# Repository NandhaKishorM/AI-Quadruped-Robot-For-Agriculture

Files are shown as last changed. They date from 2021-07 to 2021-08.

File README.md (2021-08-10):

# AI-Quadruped-Robot-For-Agriculture
## Problem statement
Massive investment on agrochemicals from the farmers’ end on crops for protection against crop health issues, diseases, and pest attacks, leading to high chemical residue content in the final product, thus reducing the quality of the produce, productivity, and polluting the farm environment. Also large use of water into crops leading to unwanted wastage of water.

## Solution
For the farmers cultivating crops, an **OAK-D enabled quadruped robot** with **robotic arm** to effectively spray **water/pesticides/insecticides** on the crops by identifying the **crop or the pests**, thus saving farmers investment on agrochemicals and water, utilizing the depth capability to detect the pest and analyze the pest infection in the process.

# Software Installation - Agribot
We followed the GitHub repo by Mike4192 for this version. Go to this [link](https://github.com/mike4192/spotMicro) to learn more.
The default implementation is on **Raspberry Pi 3 Model B and ROS kinetic**, since we used **Nvidia Jetson Nano** we invested some time on migrating to **ROS melodic**.
After installing ROS melodic on Nvidia Jetson Nano, run,
```sh
git clone https://github.com/kishorkuttan/AI-Quadruped-Robot-For-Agriculture.git
source /opt/ros/kinetic/setup.bash 
mkdir -p ~/catkin_temp  
cp -a /path/to/AI-Quadruped-Robot-For-Agriculture/src/ ~/catkin_temp/
catkin build
source devel/setup.bash
```
If you find errors during catkin build install necessary libraries or directly copy the libraries to **/src/** folder and re run catkin_build

## 3D prints
### Robot
Go to this [link](https://www.thingiverse.com/thing:3445283) for spot micro 3D print files. We made slight modification due to stability and structural issues in the default print.

### Arm
The files are under the folder /Arm 3D print stl files/

## Connection
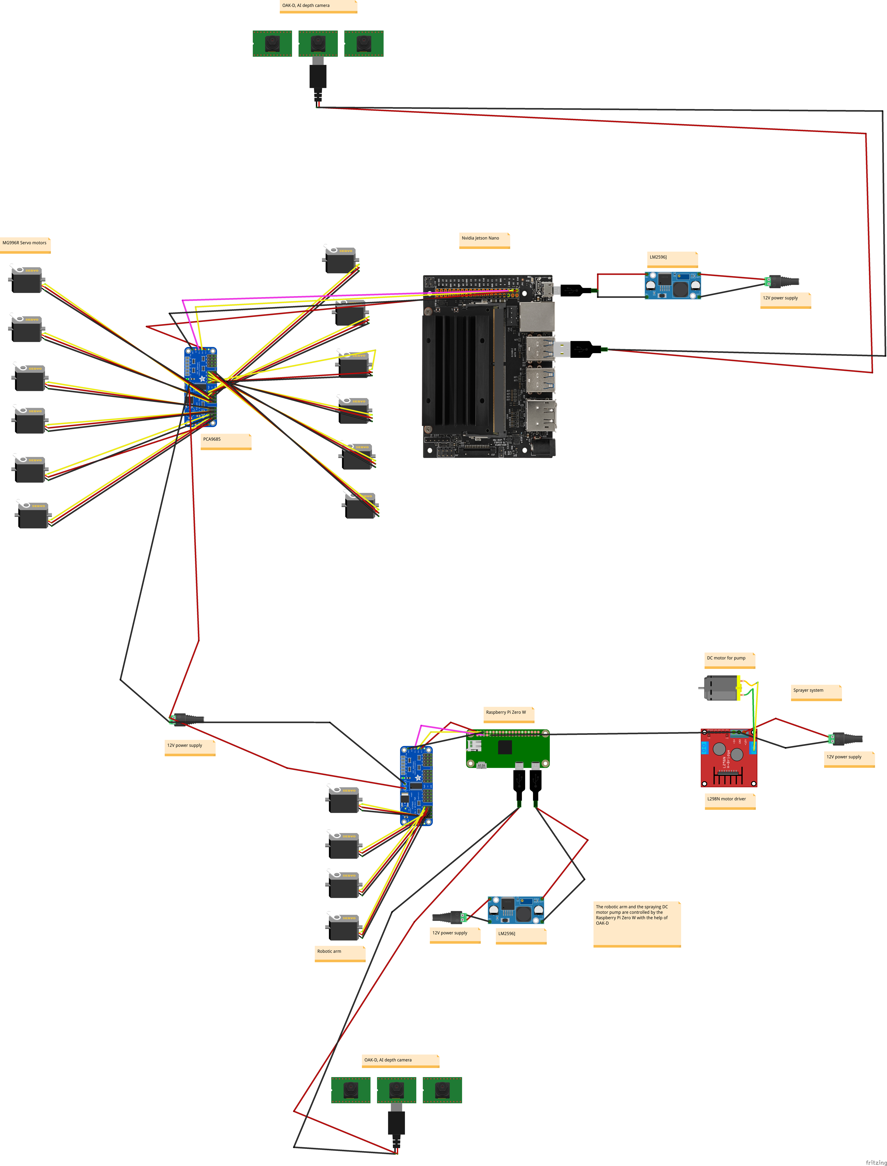
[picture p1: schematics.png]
at text

## The Robotic Arm And Sprayer System
Connect as per the diagram and control the Raspberry Pi Zero W through VNC and run,
```sh
python arm_and_spray.py
```
In this script it calculates angles for servo motors using IK and also starts the DC motor pump after getting the x,y,z location data from OAK-D.

<p float="left">
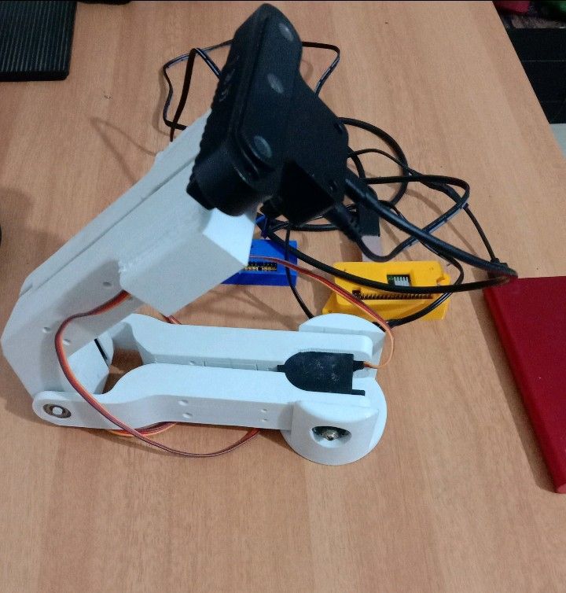
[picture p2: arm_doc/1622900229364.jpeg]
  
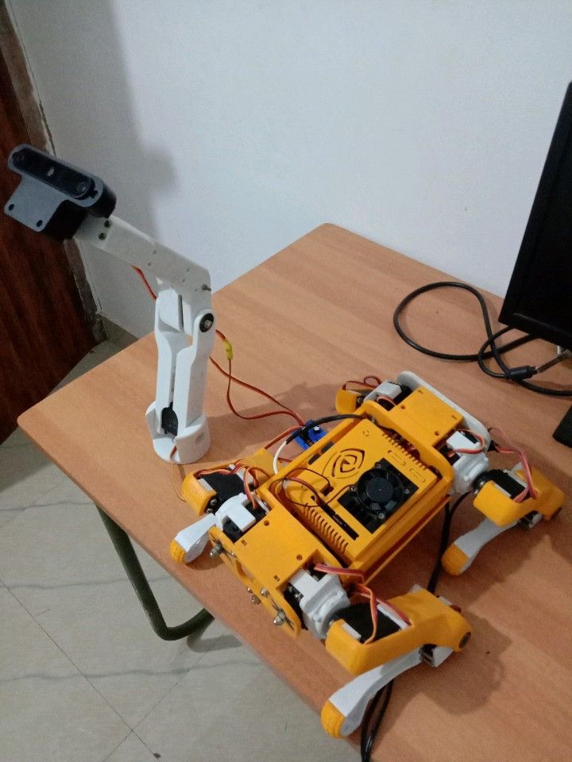
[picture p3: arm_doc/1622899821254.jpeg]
   
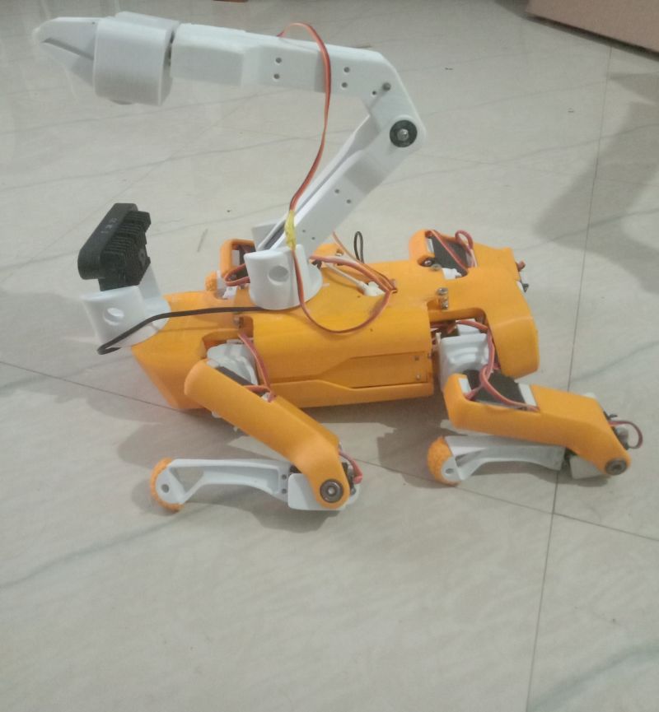
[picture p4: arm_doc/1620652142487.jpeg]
  
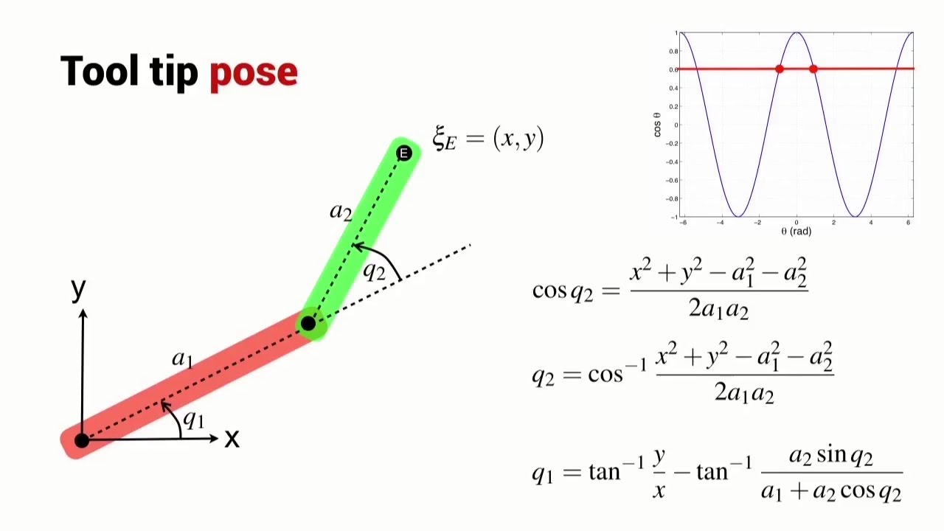
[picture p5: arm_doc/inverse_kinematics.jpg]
    
</p>

### Test OAK-D
connect the OAK-D to the host
```sh
python spatial_mobilenet.py

```
## Demo

https://user-images.githubusercontent.com/48623612/127535646-96b2c777-e888-43cb-af1a-77d663f8487b.mp4

https://user-images.githubusercontent.com/48623612/127535906-9ffb2053-86a3-4153-b496-3118d2ea1060.mp4

https://user-images.githubusercontent.com/48623612/128687662-2845c66a-45d7-49c7-8cf9-19cea187af5c.mp4

### Pest detection
#### Test
```sh
python spatial_mobilenet_custom.py
```
#### Train
Pest detection TensorFlow 1.x pipeline


https://user-images.githubusercontent.com/48623612/128688979-6633d1d9-b441-4c8c-9f94-d753bce6091c.mp4

## Inbuilt OAK-D IMU utilization
Run

```sh
python gyro visualization
```

https://user-images.githubusercontent.com/48623612/127535856-a1a527a5-7e4c-46dc-a450-e32995b7074e.mp4

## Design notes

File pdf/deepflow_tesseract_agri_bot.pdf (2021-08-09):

# AGRI ROBOT

TEAM: DEEPFLOW TESSERACT

# AI Quadruped Robot

For the farmers cultivating crops, an | OAK-D enabled quadruped robot | with | robotic
arm | to effectively | spray water/pesticides/insecticides | on the crops by | identifying
the | crop or the pests, thus saving farmers investment on agrochemicals and

water, utilizing the depth capability to detect the pest and analyze the pest infection

in the process.

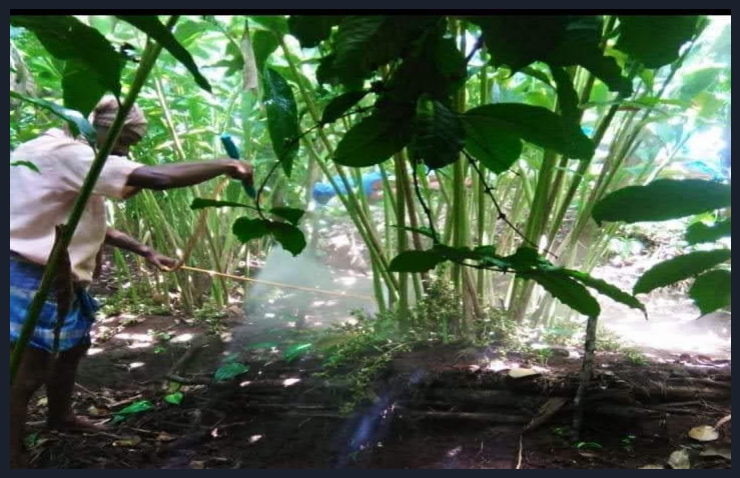
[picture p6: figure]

Traditional pesticide spraying

## 3D printing and initial prototyping

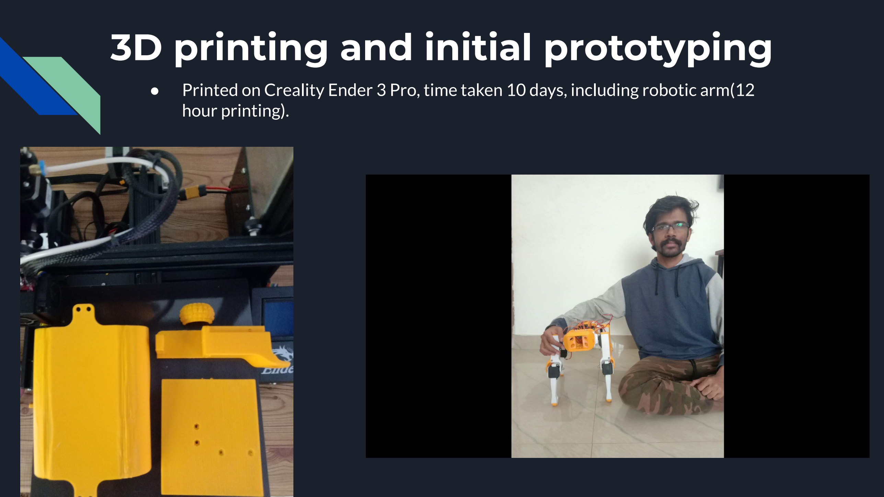
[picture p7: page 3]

- Printed on Creality Ender 3 Pro, time taken 10 days, including robotic arm(12 hour printing).

## Design phase - 1

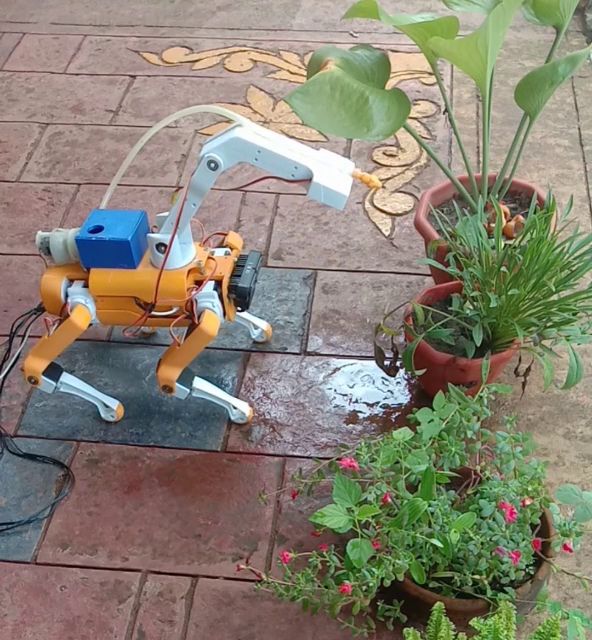
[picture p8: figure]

1. Developed the Bot with hobby servos(MG996R)and controlled it through ROS
2. Attached AI depth camera and an arm for spraying and analysis, controlling through VNC viewer through the PC.
3. All the power are supplied externally, batteries not included due to the small load capacity of the servos and the PLA filaments, broken couple of legs.

## Design phase - 2

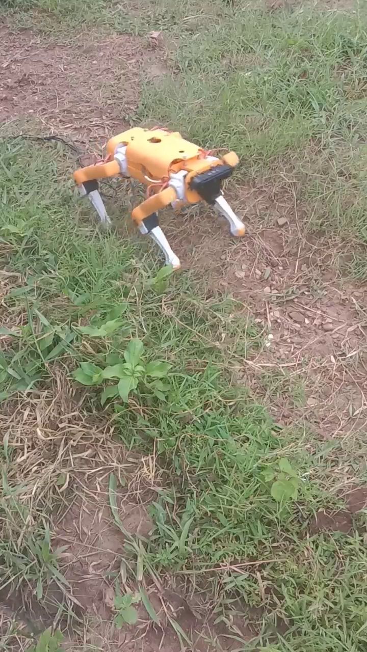
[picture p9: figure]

- Walking gaits on a grassy terrain using ROS melodic on Nvidia Jetson Nano, with a keyboard and real-time camera feed using OAK-D.
- In walk command mode, the keys w and s
| are used to control forward speed, a and d
to control side speed, and q and e to control yaw rate. u is used to exiting back to stand mode.

## Design phase - 3

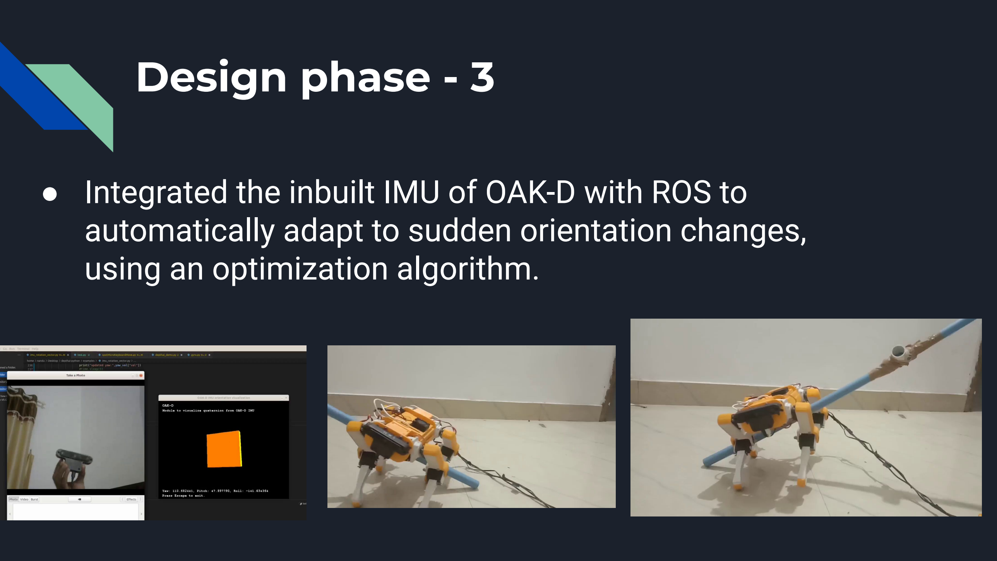
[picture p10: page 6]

- Integrated the inbuilt IMU of OAK-D with ROS to automatically adapt to sudden orientation changes, using an optimization algorithm.

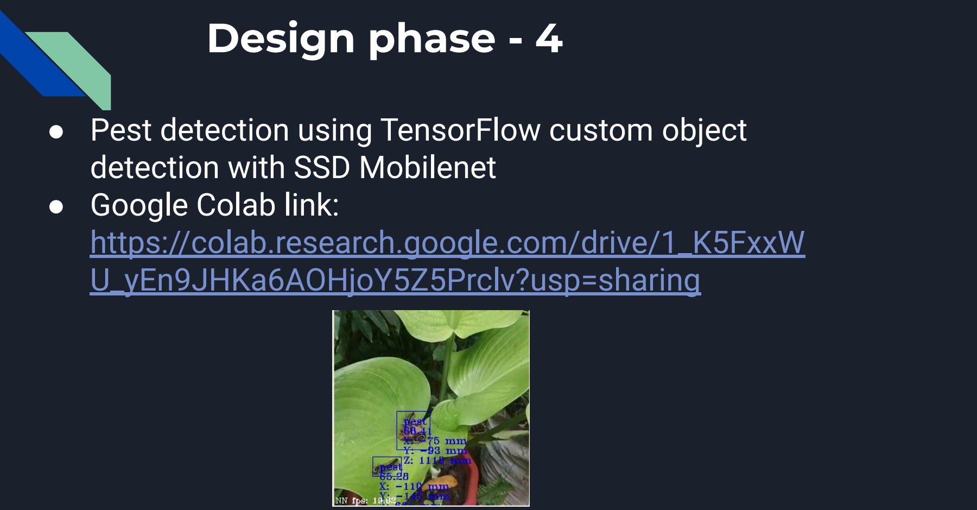
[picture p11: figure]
Design phase - 4; detection with SSD Mobilenet ● Google Colab link:; U_yEn9JHKa6AOHjoY5Z5Prclv?usp=sharing

- Pest detection using TensorFlow custom object

https://colab.research.google.com/drive/1_K5FxxW

## Robot without sprayer system

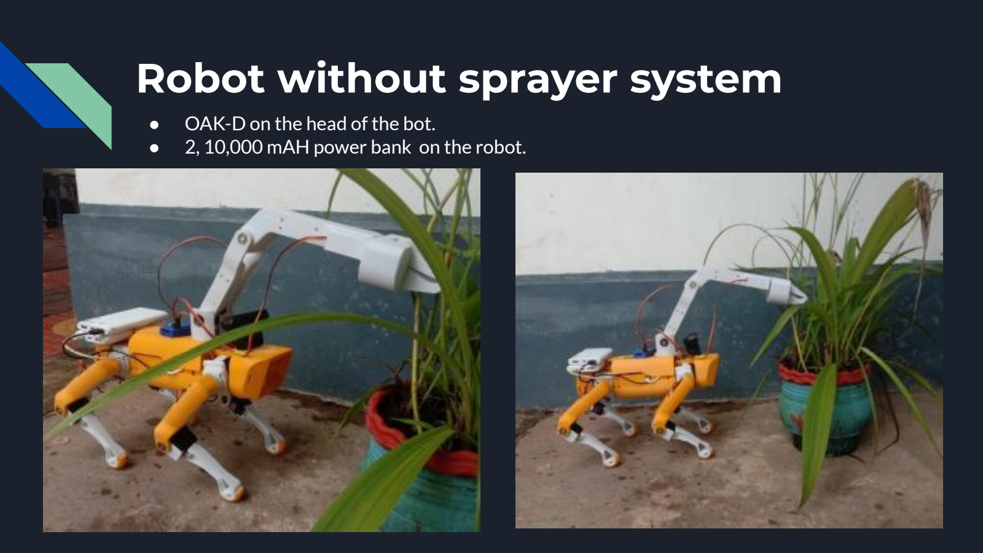
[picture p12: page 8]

- OAK-D on the head of the bot.
- 2, 10,000 mAH power bank on the robot.

## Robot with Sprayer System

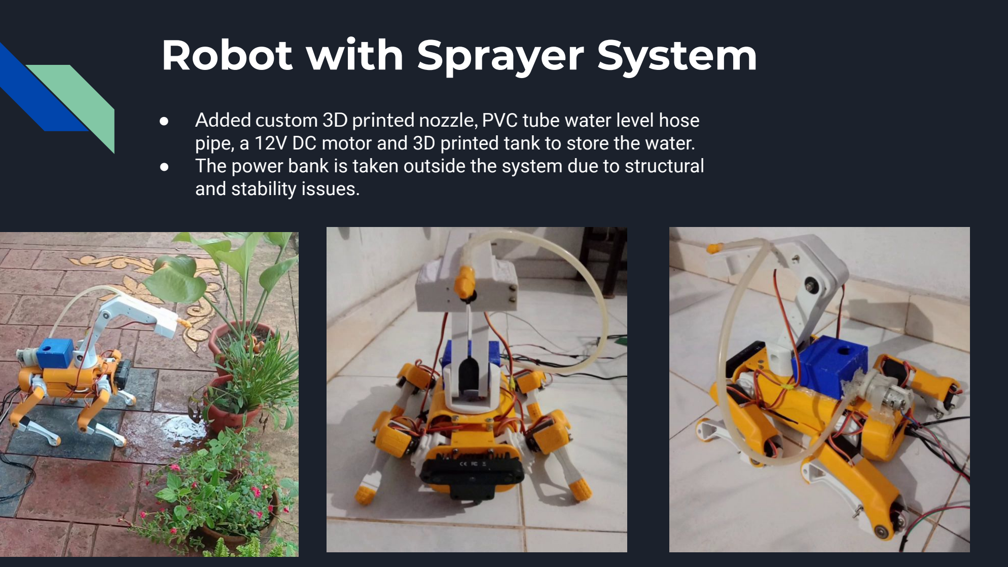
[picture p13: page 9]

- Added custom 3D printed nozzle, PVC tube water level hose pipe, a 12V DC motor and 3D printed tank to store the water.
- The power bank is taken outside the system due to structural and stability issues.

## The Robotic Arm

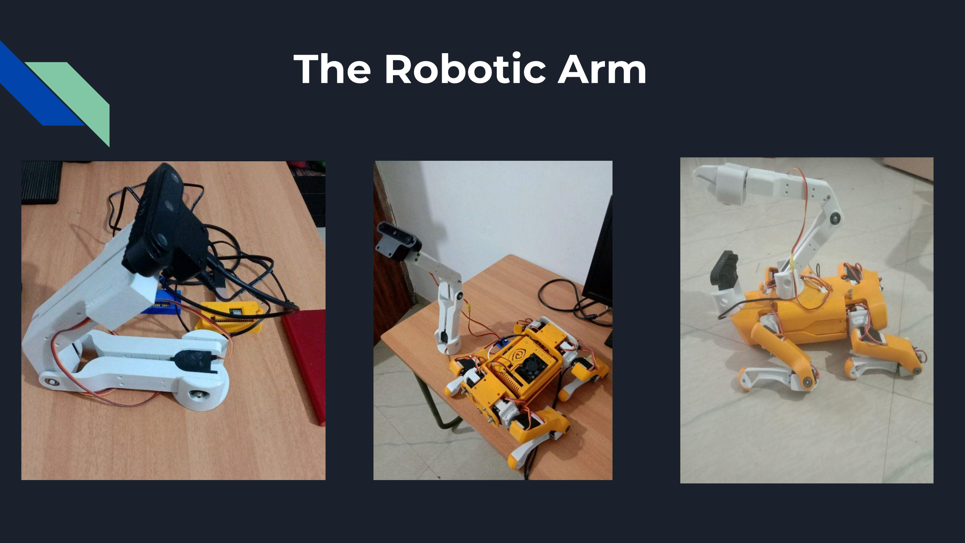
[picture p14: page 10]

## Adding Vision With Robotics

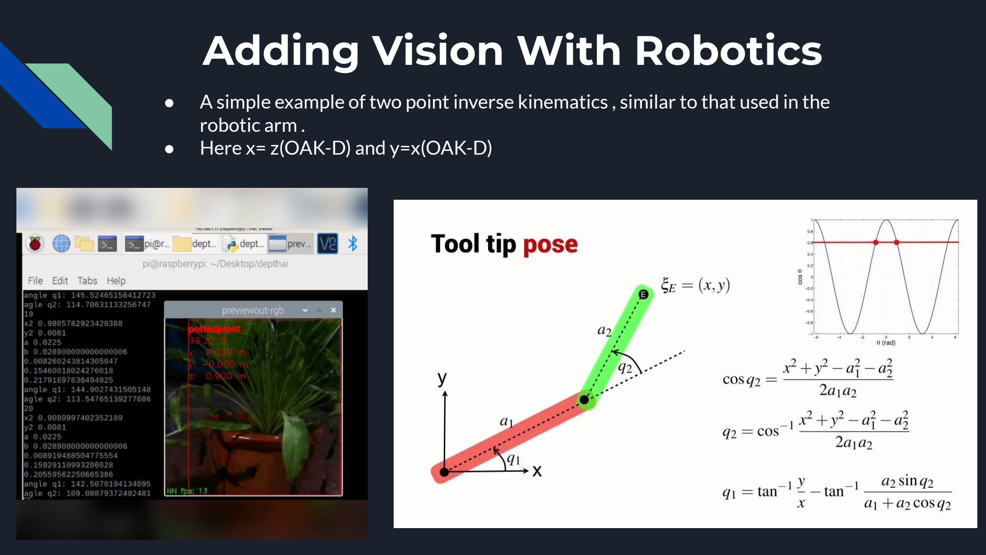
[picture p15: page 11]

- A simple example of two point inverse kinematics , similar to that used in the robotic arm .
- Here x= z(OAK-D) and y=x(OAK-D)

## GitHub Link

https://github.com/kishorkuttan/AI-Quadruped-Ro bot-For-Agriculture (https://github.com/kishorkuttan/AI-Quadruped-Robot-For-Agriculture)

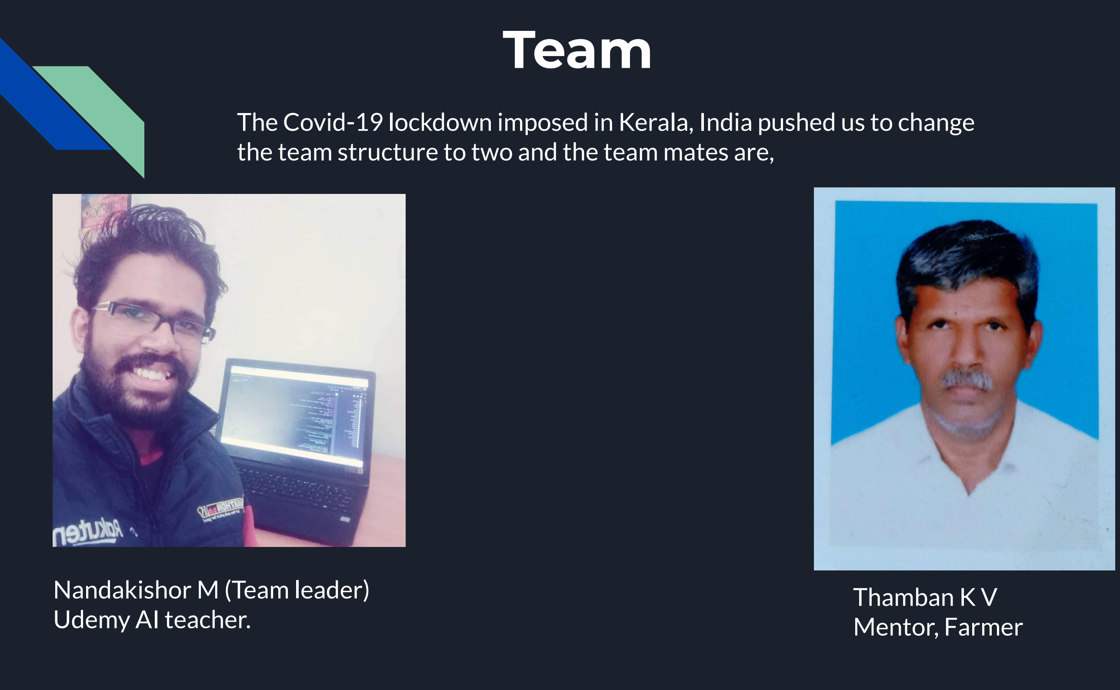
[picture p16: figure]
Team; Nandakishor M (Team leader) Udemy AI teacher.; Thamban K V Mentor, Farmer

The Covid-19 lockdown imposed in Kerala, India pushed us to change the team structure to two and the team mates are,

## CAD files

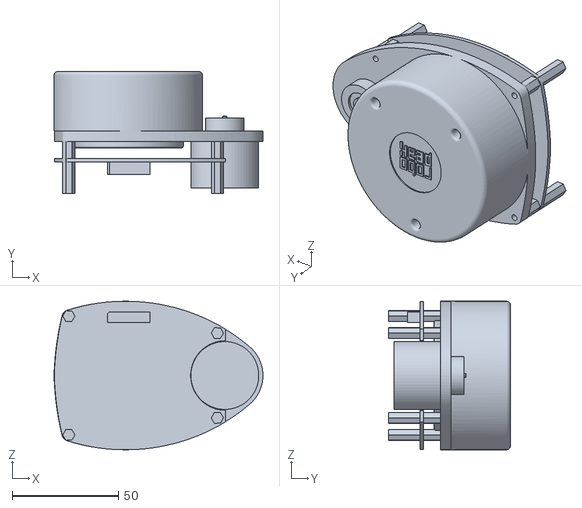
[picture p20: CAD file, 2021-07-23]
src/spot_micro_rviz/urdf/stl/rplidar_main.STL
98.5 x 57.7 x 70.0

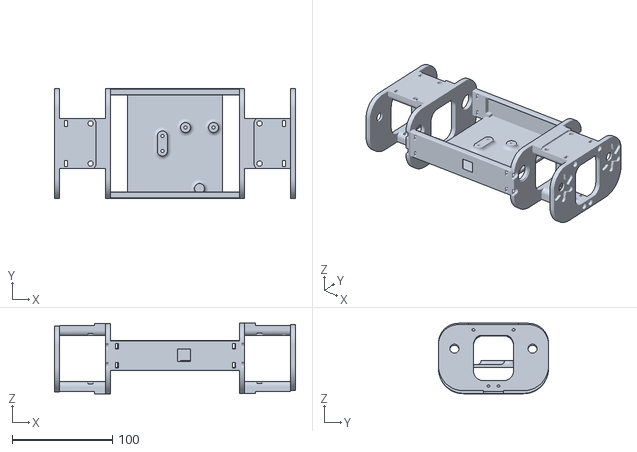
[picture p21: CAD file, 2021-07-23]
src/spot_micro_rviz/urdf/stl/mainbody.stl
240.7 x 110.0 x 70.4

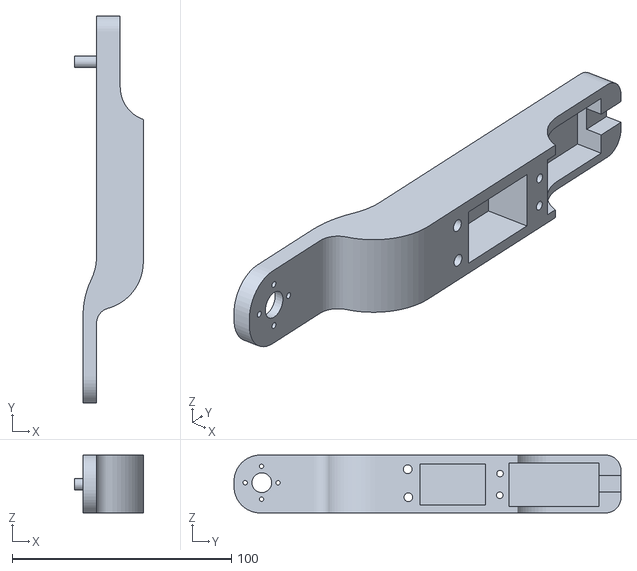
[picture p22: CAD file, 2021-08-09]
Arm 3D print stl files/Arm 1B.stl
31.4 x 176.6 x 26.5

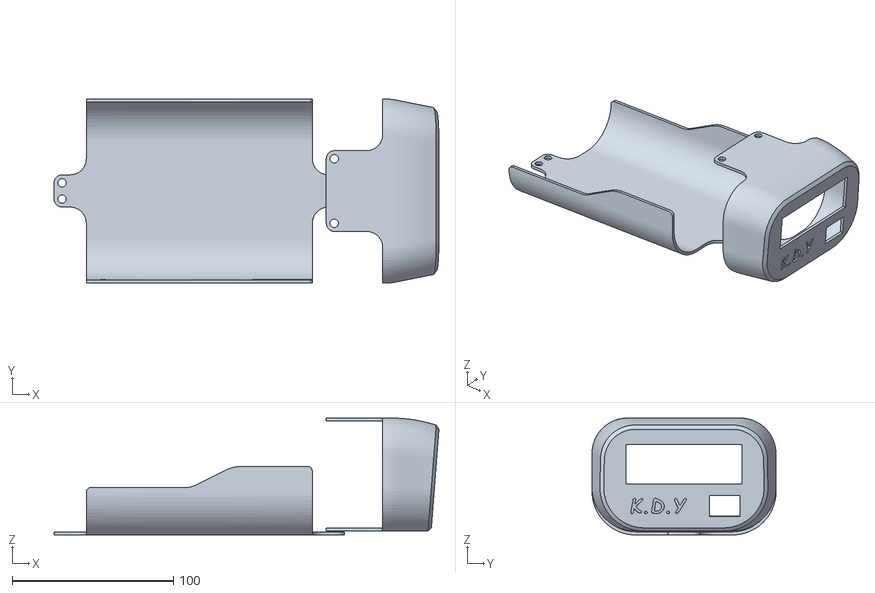
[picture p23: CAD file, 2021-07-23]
src/spot_micro_rviz/urdf/stl/backpart.stl
238.4 x 114.1 x 72.5

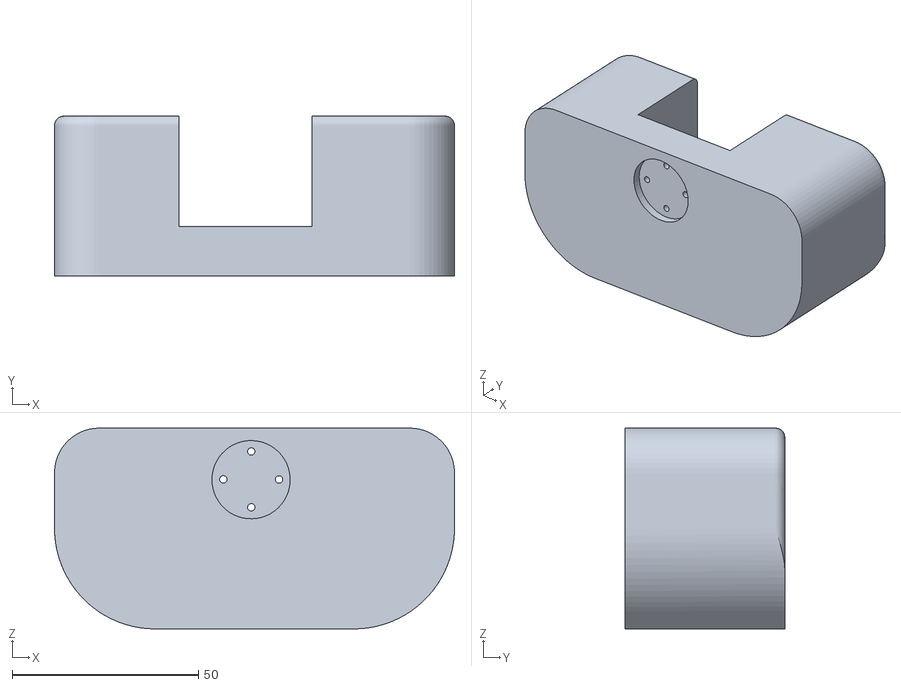
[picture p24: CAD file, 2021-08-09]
Arm 3D print stl files/Head A.stl
107.3 x 42.9 x 53.9

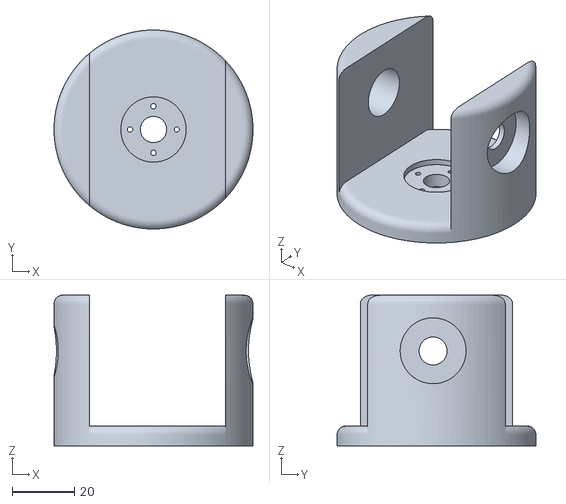
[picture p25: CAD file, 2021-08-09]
Arm 3D print stl files/Rotating Base.stl
64.0 x 64.0 x 48.5

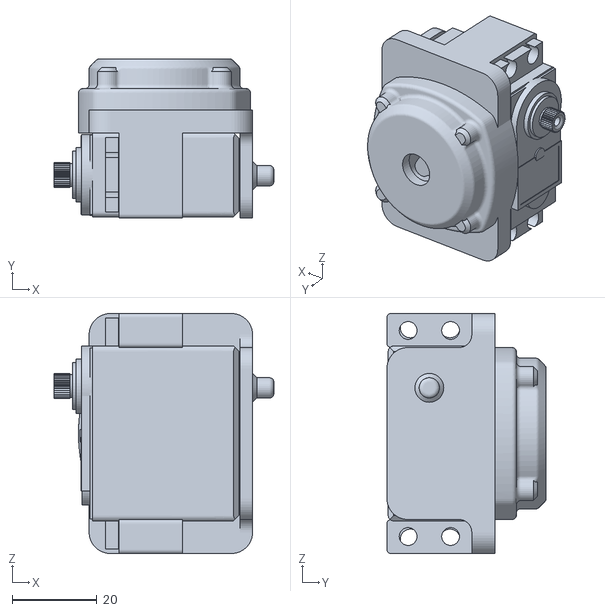
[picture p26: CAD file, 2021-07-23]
src/spot_micro_rviz/urdf/stl/rshoulder.stl
51.7 x 37.5 x 56.5

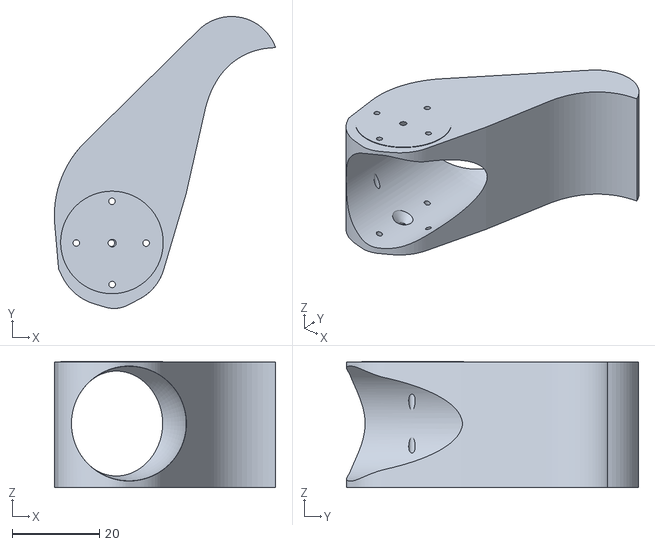
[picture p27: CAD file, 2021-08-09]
Arm 3D print stl files/Head B.stl
50.6 x 66.8 x 28.9

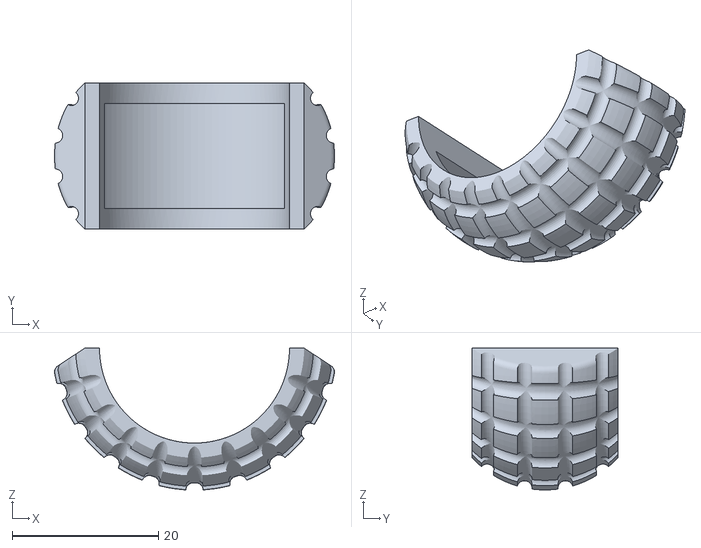
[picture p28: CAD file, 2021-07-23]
src/spot_micro_rviz/urdf/stl/foot.stl
38.3 x 20.0 x 19.4

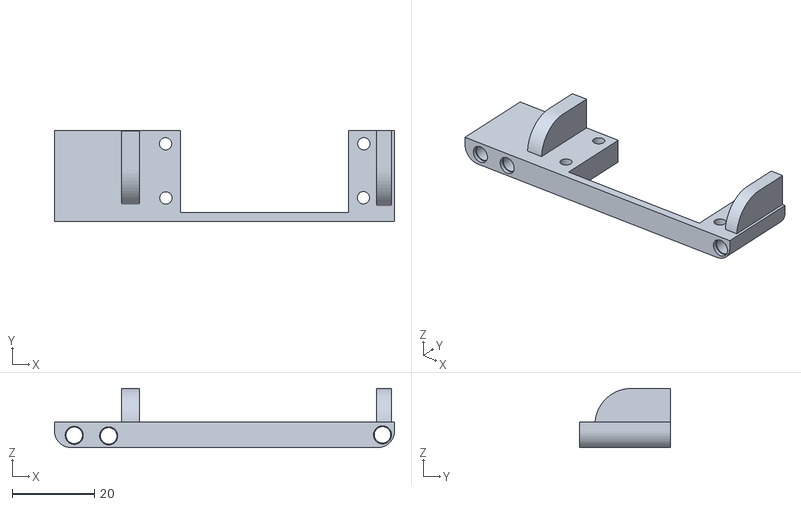
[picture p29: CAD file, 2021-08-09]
Arm 3D print stl files/Base Motor Support.stl
82.6 x 22.1 x 14.4

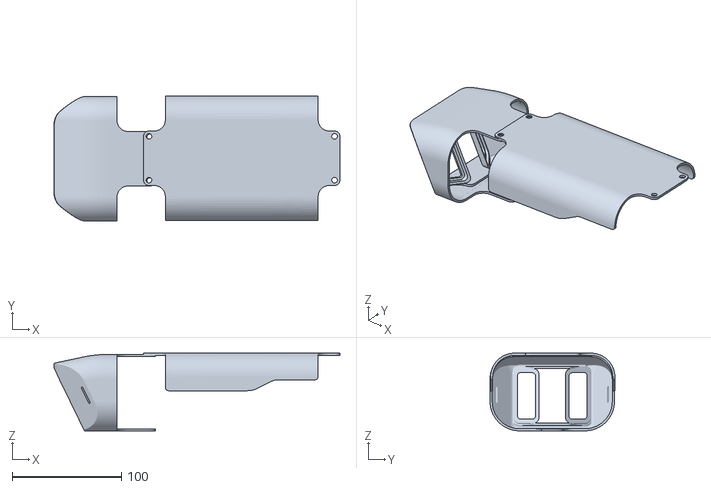
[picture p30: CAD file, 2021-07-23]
src/spot_micro_rviz/urdf/stl/frontpart.stl
262.0 x 114.5 x 71.2

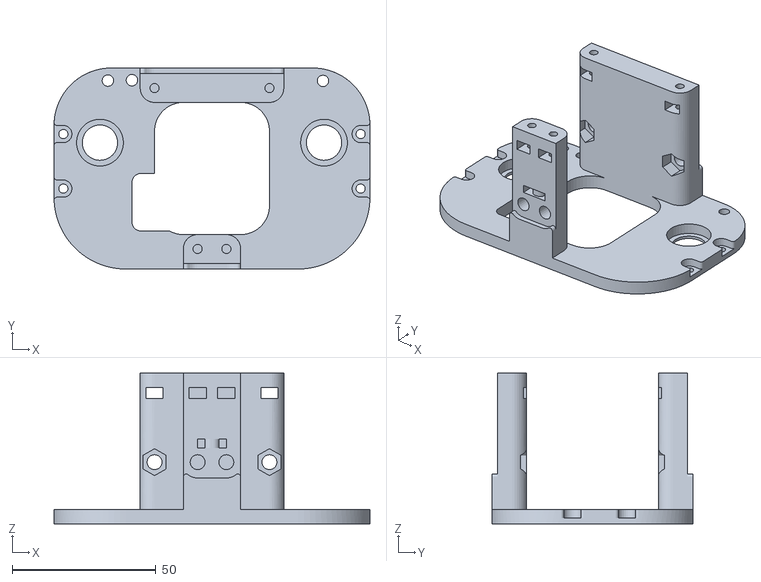
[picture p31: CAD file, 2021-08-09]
Arm 3D print stl files/Front_Inner_Shoulder.stl
110.0 x 70.0 x 52.5

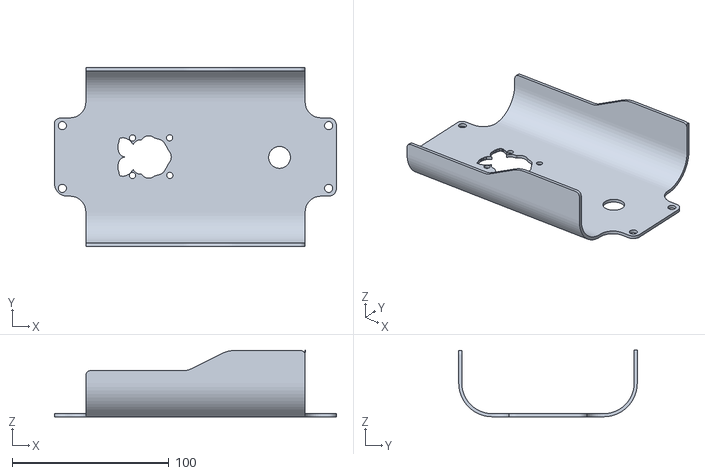
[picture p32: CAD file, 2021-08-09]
Arm 3D print stl files/Cover_TOP.stl
180.0 x 114.0 x 42.5

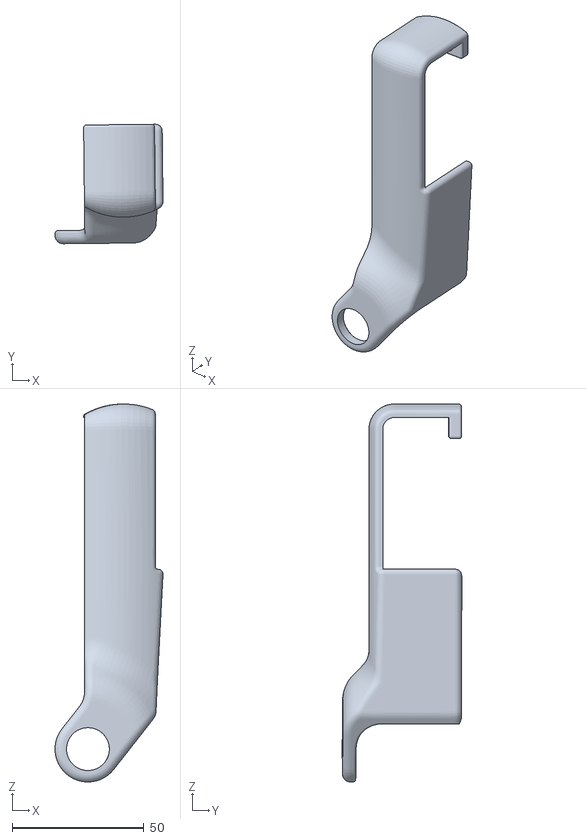
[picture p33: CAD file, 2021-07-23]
src/spot_micro_rviz/urdf/stl/larm_cover.stl
41.0 x 45.4 x 143.5

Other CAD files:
Arm 3D print stl files/Forward Arm A.stl
src/spot_micro_rviz/urdf/stl/lshoulder.stl
Arm 3D print stl files/Head C.stl
src/spot_micro_rviz/urdf/stl/rarm.stl
Arm 3D print stl files/Arm 1.stl
Arm 3D print stl files/Forward Arm B.stl
src/spot_micro_rviz/urdf/stl/larm.stl
src/spot_micro_rviz/urdf/stl/lfoot.stl
src/spot_micro_rviz/urdf/stl/rarm_cover.stl
src/spot_micro_rviz/urdf/stl/rfoot.stl

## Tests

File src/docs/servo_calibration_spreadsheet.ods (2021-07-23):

Servo | Position 1 PWM | Position 2 PWM | Position 1 Angle | Position 2 Angle | Slope (pwm/deg) | Center PWM Val | Calculated Angle at Center PWM Value | PWM val for negative max servo angle from center | PWM val for max servo angle from center | Range | Direction | Link Description
1 | 107 | 310 | 0 | 90 | 2.26 | 306 | 88.23 | 119.92 | 492.08 | 372.2 | 1 | Right front lower leg | Values in bold used for servo configuration
2 | 371 | 159 | 0 | -90 | 2.36 | 306 | -27.59 | 111.67 | 500.33 | 388.7 | 1 | Right front upper leg
3 | 293 | 401 | 0 | -45 | -2.40 | 306 | -5.42 | 504.00 | 108.00 | 396.0 | -1 | Right front hip
4 | 100 | 316 | 0 | 90 | 2.40 | 306 | 85.83 | 108.00 | 504.00 | 396.0 | 1 | Right back lower leg
5 | 175 | 391 | -90 | 0 | 2.40 | 306 | -35.42 | 108.00 | 504.00 | 396.0 | 1 | Right back upper leg
6 | 205 | 317 | -45 | 0 | 2.49 | 306 | -4.42 | 100.67 | 511.33 | 410.7 | 1 | Right back hip
7 | 268 | 481 | -90 | 0 | 2.37 | 306 | -73.94 | 110.75 | 501.25 | 390.5 | 1 | Left back lower leg
8 | 214 | 428 | 0 | 90 | 2.38 | 306 | 38.69 | 109.83 | 502.17 | 392.3 | 1 | Left back upper leg
9 | 305 | 407 | 0 | -45 | -2.27 | 306 | -0.44 | 493.00 | 119.00 | 374.0 | -1 | Left back hip
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

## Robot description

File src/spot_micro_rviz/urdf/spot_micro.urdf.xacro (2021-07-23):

<?xml version="1.0"?>
<robot xmlns:xacro="http://www.ros.org/wiki/xacro" name="spot_micro_rviz">

  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

  <xacro:property name="body_length" value="0.140" />
  <xacro:property name="body_width" value="0.110" />
  <xacro:property name="body_height" value="0.070" />

  <xacro:property name="lidar_length" value="0.0985" />
  <xacro:property name="lidar_width" value="0.0577" />
  <xacro:property name="lidar_height" value="0.070" />


  <xacro:property name="front_length" value="0.058" />
  <xacro:property name="rear_length" value="0.040" />

  <xacro:property name="shoulder_length" value="0.044" />
  <xacro:property name="shoulder_width" value="0.038" />

  <xacro:property name="leg_length" value="0.1075" />
  <xacro:property name="foot_length" value="0.130" />

  <xacro:property name="toe_radius" value="0.020" />
  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
  <xacro:property name="toe_width" value="0.020" />
  <xacro:property name="shift" value="0.055" />
  <xacro:property name="shiftx" value="0.093" />
  <xacro:property name="shifty" value="0.039" />

  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

  <xacro:macro name="gen_shoulder" params="name left">
    <link name="${name}">
      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
      <inertial>
        <mass value="0.10"/>
        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
      </inertial>
    </link>
  </xacro:macro>

  <xacro:macro name="gen_shoulder_joint" params="pos shiftx shifty">
    <joint name="${pos}_shoulder" type="revolute">
      <parent link="base_link"/>
      <child link="${pos}_shoulder_link"/>
      <axis xyz="1 0 0"/>
      <origin rpy="0 0 0" xyz="${shiftx} ${shifty} 0"/>
      <limit effort="1000.0" lower="-0.548" upper="0.548" velocity="0.7"/>
      <dynamics damping="0.0" friction="0.5"/>
    </joint>
  </xacro:macro>

  <xacro:macro name="gen_leg" params="name left">
    <link name="${name}_cover">
      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
    </link>
    <link name="${name}">
      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
      <inertial>
        <mass value="0.15"/>
        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
      </inertial>
    </link>
  </xacro:macro>

  <xacro:macro name="gen_leg_joint" params="pos shift">
    <joint name="${pos}_leg" type="revolute">
      <parent link="${pos}_shoulder_link"/>
      <child link="${pos}_leg_link"/>
      <axis xyz="0 1 0"/>
      <origin rpy="0 0 0" xyz="0 ${shift} 0"/>
      <limit effort="1000.0" lower="-2.666" upper="1.548" velocity="0.5"/>
      <dynamics damping="0.0" friction="0.0"/>
    </joint>

    <joint name="${pos}_leg_cover_joint" type="fixed">
    <parent link="${pos}_leg_link"/>
    <child link="${pos}_leg_link_cover"/>
        <origin xyz="0 0 0"/>
  </joint>  
  </xacro:macro>

  <xacro:macro name="gen_foot" params="name left">
    <link name="${name}">
      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
      <inertial>
        <mass value="0.1"/>
        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
      </inertial>
    </link>
  </xacro:macro>

  <xacro:macro name="gen_foot_joint" params="pos">
    <joint name="${pos}_foot" type="revolute">
      <parent link="${pos}_leg_link"/>
      <child link="${pos}_foot_link"/>
      <axis xyz="0 1 0"/>
      <origin rpy="0 0 0" xyz="0 0 -${leg_length}"/>
      <limit effort="1000.0" lower="-2.6" upper="0.1" velocity="0.5"/>
      <dynamics damping="0.0" friction="0.5"/>
    </joint>
  </xacro:macro>

  <xacro:macro name="gen_toe" params="name">
    <link name="${name}">
      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
      <inertial>
        <mass value="0.05"/>
        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
      </inertial>
    </link>
  </xacro:macro>

 <xacro:macro name="gen_toe_joint" params="pos">
    <joint name="${pos}_toe" type="fixed">
      <parent link="${pos}_foot_link"/>
      <child link="${pos}_toe_link"/>
      <origin xyz="0 0 -${foot_length}"/>
    </joint>
  </xacro:macro>

  <xacro:macro name="gen_full_leg_joint" params="pos shiftx shifty shift left">
    <xacro:gen_shoulder name="${pos}_shoulder_link" left="${left}"/>
    <xacro:gen_leg name="${pos}_leg_link" left="${left}"/>
    <xacro:gen_foot name="${pos}_foot_link" left="${left}"/>
    <xacro:gen_toe name="${pos}_toe_link"/>

    <xacro:gen_shoulder_joint pos="${pos}" shiftx="${shiftx}" shifty="${shifty}"/>
    <xacro:gen_leg_joint pos="${pos}" shift="${shift}"/>
    <xacro:gen_foot_joint pos="${pos}"/>
    <xacro:gen_toe_joint pos="${pos}"/>
  </xacro:macro>

  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

  <link name="base_link">
    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
    <inertial>
      <mass value="2.80"/>
      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
    </inertial>
  </link>

  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

   <link name="lidar_link">
    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
    <inertial>
      <mass value="0.50"/>
      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
    </inertial>
  </link>
  <joint name="base_lidar" type="fixed">
    <parent link="base_link"/>
    <child link="lidar_link"/>
        <origin xyz="0 0 ${body_height/2}"/>
  </joint>  

  <link name="rear_link">
    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
    <inertial>
      <mass value="0.20"/>
      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
    </inertial>
  </link>
  <joint name="base_rear" type="fixed">
    <parent link="base_link"/>
    <child link="rear_link"/>
  </joint>

  <link name="front_link">
    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
    <inertial>
      <mass value="0.20"/>
      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
    </inertial>
  </link>
  <joint name="base_front" type="fixed">
    <parent link="base_link"/>
    <child link="front_link"/>
  </joint>

  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

  <xacro:gen_full_leg_joint pos="front_left" shiftx="${shiftx}" shifty="${shifty}" shift="${shift}" left="true"/>
  <xacro:gen_full_leg_joint pos="front_right" shiftx="${shiftx}" shifty="-${shifty}" shift="-${shift}" left="false"/>
  <xacro:gen_full_leg_joint pos="rear_left" shiftx="-${shiftx}" shifty="${shifty}" shift="${shift}" left="true"/>
  <xacro:gen_full_leg_joint pos="rear_right" shiftx="-${shiftx}" shifty="-${shifty}" shift="-${shift}" left="false"/>

</robot>

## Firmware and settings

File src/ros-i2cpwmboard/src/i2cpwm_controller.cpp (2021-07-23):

/**
 *
   \file
   \brief      controller for I2C interfaced 16 channel PWM boards with PCA9685 chip
   \author     Bradan Lane Studio <info@bradanlane.com>
   \copyright  Copyright (c) 2016, Bradan Lane Studio
 
  Redistribution and use in source and binary forms, with or without
  modification, are permitted provided that the following conditions are met:
      - Redistributions of source code must retain the above copyright
        notice, this list of conditions and the following disclaimer.
      - Redistributions in binary form must reproduce the above copyright
        notice, this list of conditions and the following disclaimer in the
        documentation and/or other materials provided with the distribution.
      - The name of Bradan Lane, Bradan Lane Studio nor the
        names of its contributors may be used to endorse or promote products
        derived from this software without specific prior written permission.
 
  THIS SOFTWARE IS PROVIDED BY THE COPYRIGHT HOLDERS AND CONTRIBUTORS "AS IS" AND
  ANY EXPRESS OR IMPLIED WARRANTIES, INCLUDING, BUT NOT LIMITED TO, THE IMPLIED
  WARRANTIES OF MERCHANTABILITY AND FITNESS FOR A PARTICULAR PURPOSE ARE
  DISCLAIMED. IN NO EVENT SHALL BRADAN LANE STUDIOS BE LIABLE FOR ANY
  DIRECT, INDIRECT, INCIDENTAL, SPECIAL, EXEMPLARY, OR CONSEQUENTIAL DAMAGES
  (INCLUDING, BUT NOT LIMITED TO, PROCUREMENT OF SUBSTITUTE GOODS OR SERVICES;
  LOSS OF USE, DATA, OR PROFITS; OR BUSINESS INTERRUPTION) HOWEVER CAUSED AND
  ON ANY THEORY OF LIABILITY, WHETHER IN CONTRACT, STRICT LIABILITY, OR TORT
  (INCLUDING NEGLIGENCE OR OTHERWISE) ARISING IN ANY WAY OUT OF THE USE OF THIS
  SOFTWARE, EVEN IF ADVISED OF THE POSSIBILITY OF SUCH DAMAGE.
 
  Please send comments, questions, or patches to info@bradanlane.com
 
*/

/**
\mainpage
 
 Controller for I2C interfaced 16 channel PWM boards with PCA9685 chip<br/>
 Bradan Lane Studio <info@bradanlane.com><br/>
 Copyright (c) 2016, Bradan Lane Studio<br/>
 Licensed under GPLv3<br/>

--------


\section overview FILE STRUCTURE AND CODE
 
  The file is broken into sections:
    - private properties (all private properties have a leading underscore)
    - private methods (all private methods have a leading underscore)
    - public topic subscribers: 
		- servos_absolute()
		- servos_proportional()
		- servos_drive()
    - public services:
		- set_pwm_frequency()
		- set_active_board()
		- config_servos()
		- config_drive_mode()
		- stop_servos()
 
  The code is currently authored in C and should be rewritten as proper C++.
 
  This documentation refers to 'servo' and 'RC servo' but is equally applicable to any PWM or PPM controlled DC motor.

  All published services and topics use a one-based count syntax. For example, the first servo is '1' and the default board is '1'. 
  The hardware uses zero-based values. For example the first channel on the 16 channel 12-bit PWM board is '0' and the first I2C board is '0' with address 0x40.
  The switch from one-based to zero-based is done at the lowest level of this code. All public interactions should assume one-based values.

  _WARNING_: The code has only been tested with a single board using the default I2C address of 0x40. Once testing has been done with additional configurations, this warning will be removed or amended.

 
\section pwmservos USING PWM WITH SERVOS

  While the PCA9685 chip and related boards are called "PWM" for pulse width modulation, there use with servos
  is more accurately PPM for pulse position modulation.

  For standard 180 degree servos with a motion arc of ±90 degrees the pulse moves the servo arm to specifc position and holds it.
  For continuous motion servos, the pulse moves the servo at a specific speed. 

  The documentation will refer to positon, speed or position/speed. 
  These are interchangeable as the two terms are dependent on whether the servo is a fixed rotation servo or a continuous rotation servo and independent of the board itself.
 
  Analog RC servos are most often designed for 20ms pulses. This is achieved with a frequency of 50Hz.
  This software defaults to 50Hz. Use the set_pwm_frequncy() to change this frequency value. 
  It may be necessary or convenient to change the PWM frequency if using DC motors connected to PWM controllers. 
  It may also be convenient if using PWM to control LEDs.

  A commonly available board is the Adafruit 16 channel 12-bit PWM board or the similarly named HAT. There are similar boards as well as clones.
  All of these boards use the PCA9685 chip. Not all boards have been tested.

  The PWM boards drive LED and servos using pulse width modulation. The 12 bit interface means values are in the range of 0..4096.
  The pulse is defined as a start value and end value. When driving servos, the start point is typically 0 and the end point is the duration.

  FYI: If using more than one PWM board or when using a board with an I2C address other than the default 0x40, 
  the set_active_board() service must be used before using other services or topics from this package.
 

\section configuration CONFIGURING SERVOS

  The tolerance of the resistors in RC servos means each servo may have a slightly different center point.

  The servos_absolute() topic controls servos with absolute pulse start and stop values.
  This topic subscriber is not generally useful in robot operations, however it is convenient for testing and for determining configuration values.
  Use this topic to determine the center position for a standard servo or the stop position for a continuous servo.

  Also use this topic to determine the range of each servo - 
  either the ±90 postion for a standard servo or 
  the max forward and reverse speed for a continuous rotation servo.

  __note:__ The centering value and range of servos is dependent on the pulse frequency. 
  If you use set_pwm_frequency() to change the system value, you will need to determine new center and range values.

  The servos_proportional() topic controls servos through their range of motion using values between -1.0 and 1.0.
  Use the config_servos() service to set the center values, range values, and directions of rotation for servos.
  This enables servo motion to be generalized to a standard proportion of ±1.0.
  Use of the config_servos() service is required before proportional control is available. 

  
\section drivemode ROBOT DRIVE MODE

  In addition to absolute and proportional topics for controling servos, this package provides support for the geometry 'Twist' message.
  The servos_drive() topic handles the calculations to convert linear and angular data to servo drive data.

  Drive mode requires details for each servo. Use of the config_servos() before using drive mode.

  The geometry_msgs::Twist providesf linear and angular velocity measured in m/s (meters per second) and r/s (radians per second) respectively.
  To perform the necessary calculations, data about the drive system is required.
  Use config_drive_mode() to provide the RPM of the drive wheels, their radius, and the track distance between left and right. These values determine speed and turn rates.

  Specifiy the desired drive mode with the `mode` property to cofig_drive_mode(). This package supports three drive modes:
  
    -# __ackerman__ - A single velocity drive using one or more servos with a non-drive servo controlling steering.
    -# __differential__ - Skid steer or track steer using one or more  servos for each of the left and right sides.
	The result is full speed forward or reverse, min/max radius turns, and the ability to perform zero-radius turns
    -# __mecanum__ - Independent drive on all four wheel capable of holonomic drive - moving in any combination of forward, reverse, turning, and sideways. 
	The servos are assigned positons for left-front, right-front, left-rear, and right-rear wheels. This mode supports
	similar drive characteristics to differential drive with the additional of lateral motion.


  The servos on the PWM board are assigned to their respective drive positons using the config_drive_mode() service.
  The applicable servos are assigned positions as follows:
  
    positon | ackerman | differential | mecanum
    --------|----------|--------------|--------
    position 1 corresponds to | drive | left | left-front
    position 2 corresponds to | | right | right-front
    position 3 corresponds to | | | left-rear
    position 4 corresponds to | | | right-rear
  
  The drive topic requires that use of both the config_servos() service and config_drive_mode() service before drive mode will result in expected behavior.

  All non-drive servos may still be operated with the proportion or absolute topics.

  __Note:__ _This controller does not implement encoders for PWM motors. There is no guarantee that the drive velocity will exactly match the Twist message input.
  While this may not be acceptable for a commercial or scientific application, it may not be of convern for education and amatuer competitions. Encoders could be added and feedback applied to the PWM values.
  Additionally, when drive control is a product of positional feedback - such as line following and navigation via camera vision - drive encoders are usually not required._

  The stop_servos() service is provided as convenience to stop all servos and place then is a powered off state. This is different from setting each servo to its center value.
  The stop service is useful as a safety operation.

\section testing TESTING

  Basic testing is available from the command line. Start the I2C PWM node with `roslaunch i2cpwm_board i2cpwm_node.launch` (or `roscore` and `rosrun i2cpwm_board i2cpwm_board`) and then proceed with 
  example commands contained within the documentation for each service and topic subscriber.

 */

extern "C" {
	#include <i2c/smbus.h>
}

#include <stdio.h>
#include <stdlib.h>
#include <string.h>
#include <math.h>
#include <fcntl.h>
#include <errno.h>
#include <unistd.h>
#include <sys/ioctl.h>
#include <sys/types.h>
#include <sys/stat.h>
#include <linux/i2c-dev.h>

#include <ros/ros.h>
#include <ros/console.h>

// messages used for any service with no parameters
#include <std_srvs/Empty.h>
// messages used for drive movement topic
#include <geometry_msgs/Twist.h>

// messages used for the absolute and proportional movement topics
#include "i2cpwm_board/Servo.h"
#include "i2cpwm_board/ServoArray.h"
// messages used for the servo setup service
#include "i2cpwm_board/ServoConfig.h"
#include "i2cpwm_board/ServoConfigArray.h"
// request/response of the servo setup service
#include "i2cpwm_board/ServosConfig.h"
// request/response of the drive mode service
#include "i2cpwm_board/DriveMode.h"
#include "i2cpwm_board/Position.h"
#include "i2cpwm_board/PositionArray.h"
// request/response of the integer parameter services
#include "i2cpwm_board/IntValue.h"


/// @cond PRIVATE_NO_PUBLIC DOC

typedef struct _servo_config {
    int center;
    int range;
    int direction;
    int mode_pos;
} servo_config;

typedef struct _drive_mode {
	int mode;
	float rpm;
	float radius;
	float track;
	float scale;
} drive_mode;

enum drive_modes {
    MODE_UNDEFINED      = 0,
    MODE_ACKERMAN       = 1,
    MODE_DIFFERENTIAL   = 2,
    MODE_MECANUM        = 3,
    MODE_INVALID        = 4
};

enum drive_mode_positions {
    POSITION_UNDEFINED  = 0,
    POSITION_LEFTFRONT  = 1,
    POSITION_RIGHTFRONT = 2,
    POSITION_LEFTREAR   = 3,
    POSITION_RIGHTREAR  = 4,
    POSITION_INVALID    = 5
};

#define _BASE_ADDR   0x40
#ifndef _PI
#define _PI 3.14159265358979323846
#endif
#define _CONST(s) ((char*)(s))

enum pwm_regs {
  // Registers/etc.
  __MODE1              = 0x00,
  __MODE2              = 0x01,
  __SUBADR1            = 0x02,      // enable sub address 1 support
  __SUBADR2            = 0x03,      // enable sub address 2 support
  __SUBADR3            = 0x04,      // enable sub address 2 support
  __PRESCALE           = 0xFE,
  __CHANNEL_ON_L       = 0x06,
  __CHANNEL_ON_H       = 0x07,
  __CHANNEL_OFF_L      = 0x08,
  __CHANNEL_OFF_H      = 0x09,
  __ALL_CHANNELS_ON_L  = 0xFA,
  __ALL_CHANNELS_ON_H  = 0xFB,
  __ALL_CHANNELS_OFF_L = 0xFC,
  __ALL_CHANNELS_OFF_H = 0xFD,
  __RESTART            = 0x80,
  __SLEEP              = 0x10,      // enable low power mode
  __ALLCALL            = 0x01,
  __INVRT              = 0x10,      // invert the output control logic
  __OUTDRV             = 0x04
};

#define MAX_BOARDS 62
#define MAX_SERVOS (16*MAX_BOARDS)

servo_config _servo_configs[MAX_SERVOS];    // we can support up to 62 boards (1..62), each with 16 PWM devices (1..16)
drive_mode _active_drive;					// used when converting Twist geometry to PWM values and which servos are for motion
int _last_servo = -1;

int _pwm_boards[MAX_BOARDS];                // we can support up to 62 boards (1..62)
int _active_board = 0;                      // used to determine if I2C SLAVE change is needed
int _controller_io_handle;                  // linux file handle for I2C
int _controller_io_device;                  // linux file for I2C

int _pwm_frequency = 50;                    // frequency determines the size of a pulse width; higher numbers make RC servos buzz


/// @endcond PRIVATE_NO_PUBLIC DOC



//* ------------------------------------------------------------------------------------------------------------------------------------
// local private methods
//* ------------------------------------------------------------------------------------------------------------------------------------

static float _abs (float v1)
{
	if (v1 < 0)
		return (0 - v1);
	return v1;
}

static float _min (float v1, float v2)
{
	if (v1 > v2)
		return v2;
	return v1;
}

static float _max (float v1, float v2)
{
	if (v1 < v2)
		return v2;
	return v1;
}

static float _absmin (float v1, float v2)
{
	float a1, a2;
	float sign = 1.0;
	//	if (v1 < 0)
	//		sign = -1.0;
	a1 = _abs(v1);
	a2 = _abs(v2);
	if (a1 > a2)
		return (sign * a2);
	return v1;
}

static float _absmax (float v1, float v2)
{
	float a1, a2;
	float sign = 1.0;
	//	if (v1 < 0)
	//		sign = -1.0;
	a1 = _abs(v1);
	a2 = _abs(v2);
	if (a1 < a2)
		return (sign * a2);
	return v1;
}



/**
 \private method to smooth a speed value
 
 we calculate each speed using a cosine 'curve',  this results in the output curve 
 being shallow at 'stop', full forward, and full reverse and becoming 
 more aggressive in the middle or each direction

 @param speed an int value (±1.0) indicating original speed
 @returns an integer value (±1.0) smoothed for more gentle acceleration
 */
static int _smoothing (float speed)
{
	/* if smoothing is desired, then remove the commented code  */
	// speed = (cos(_PI*(((float)1.0 - speed))) + 1) / 2;
	return speed;
}
	

/**
   \private method to convert meters per second to a proportional value in the range of ±1.0
 
   @param speed float requested speed in meters per second
   @returns float value (±1.0) for servo speed
 */
static float _convert_mps_to_proportional (float speed)
{
	/* we use the drive mouter output rpm and wheel radius to compute the conversion */

	float initial, max_rate;	// the max m/s is ((rpm/60) * (2*PI*radius))

	initial = speed;
	
	if (_active_drive.rpm <= 0.0) {
        ROS_ERROR("Invalid active drive mode RPM %6.4f :: RPM must be greater than 0", _active_drive.rpm);
		return 0.0;
	}
	if (_active_drive.radius <= 0.0) {
        ROS_ERROR("Invalid active drive mode radius %6.4f :: wheel radius must be greater than 0", _active_drive.radius);
		return 0.0;
	}

	max_rate = (_active_drive.radius * _PI * 2) * (_active_drive.rpm / 60.0);

	speed = speed / max_rate;
	// speed = _absmin (speed, 1.0);

	ROS_DEBUG("%6.4f = convert_mps_to_proportional ( speed(%6.4f) / ((radus(%6.4f) * pi(%6.4f) * 2) * (rpm(%6.4f) / 60.0)) )", speed, initial, _active_drive.radius, _PI, _active_drive.rpm);
	return speed;
}



/**
 * \private method to set a pulse frequency
 *
 *The pulse defined by start/stop will be active on all channels until any subsequent call changes it.
 *@param frequency an int value (1..15000) indicating the pulse frequency where 50 is typical for RC servos
 *Example _set_frequency (68)  // set the pulse frequency to 68Hz
 */
static void _set_pwm_frequency (int freq)
{
    int prescale;
    char oldmode, newmode;
    int res;

    _pwm_frequency = freq;   // save to global
    
	ROS_DEBUG("_set_pwm_frequency prescale");
    float prescaleval = 25000000.0; // 25MHz
    prescaleval /= 4096.0;
    prescaleval /= (float)freq;
    prescaleval -= 1.0;
    //ROS_INFO("Estimated pre-scale: %6.4f", prescaleval);
    prescale = floor(prescaleval + 0.5);
    // ROS_INFO("Final pre-scale: %d", prescale);


	ROS_INFO("Setting PWM frequency to %d Hz", freq);

    nanosleep ((const struct timespec[]){{1, 000000L}}, NULL); 


    oldmode = i2c_smbus_read_byte_data (_controller_io_handle, __MODE1);
    newmode = (oldmode & 0x7F) | 0x10; // sleep

    if (0 > i2c_smbus_write_byte_data (_controller_io_handle, __MODE1, newmode)) // go to sleep
        ROS_ERROR("Unable to set PWM controller to sleep mode"); 

    if (0 >  i2c_smbus_write_byte_data(_controller_io_handle, __PRESCALE, (int)(floor(prescale))))
        ROS_ERROR("Unable to set PWM controller prescale"); 

    if (0 > i2c_smbus_write_byte_data(_controller_io_handle, __MODE1, oldmode))
        ROS_ERROR("Unable to set PWM controller to active mode"); 

    nanosleep((const struct timespec[]){{0, 5000000L}}, NULL);   //sleep 5microsec,

    if (0 > i2c_smbus_write_byte_data(_controller_io_handle, __MODE1, oldmode | 0x80))
        ROS_ERROR("Unable to restore PWM controller to active mode");
}



/**
 * \private method to set a common value for all PWM channels on the active board
 *
 *The pulse defined by start/stop will be active on all channels until any subsequent call changes it.
 *@param start an int value (0..4096) indicating when the pulse will go high sending power to each channel.
 *@param end an int value (0..4096) indicating when the pulse will go low stoping power to each channel.
 *Example _set_pwm_interval_all (0, 108)   // set all servos with a pulse width of 105
 */
static void _set_pwm_interval_all (int start, int end)
{
    // the public API is ONE based and hardware is ZERO based
    if ((_active_board<1) || (_active_board>62)) {
        ROS_ERROR("Internal error - invalid active board number %d :: PWM board numbers must be between 1 and 62", _active_board);
        return;
    }
    int board = _active_board - 1;

    if (0 > i2c_smbus_write_byte_data (_controller_io_handle, __ALL_CHANNELS_ON_L, start & 0xFF))
        ROS_ERROR ("Error setting PWM start low byte for all servos on board %d", _active_board);
    if (0 >  i2c_smbus_write_byte_data (_controller_io_handle, __ALL_CHANNELS_ON_H, start  >> 8))
        ROS_ERROR ("Error setting PWM start high byte for all servos on board %d", _active_board);
    if (0 > i2c_smbus_write_byte_data (_controller_io_handle, __ALL_CHANNELS_OFF_L, end & 0xFF))
        ROS_ERROR ("Error setting PWM end low byte for all servos on board %d", _active_board);
    if (0 > i2c_smbus_write_byte_data (_controller_io_handle, __ALL_CHANNELS_OFF_H, end >> 8))
        ROS_ERROR ("Error setting PWM end high byte for all servos on board %d", _active_board);
}
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
int main (int argc, char **argv)
{
	// globals
	_controller_io_device = 1;	// default I2C device on RPi2 and RPi3 = "/dev/i2c-1" Orange Pi Lite = "/dev/i2c-0"
	_controller_io_handle = 0;
	_pwm_frequency = 50;		// set the initial pulse frequency to 50 Hz which is standard for RC servos

	

	ros::init (argc, argv, "i2cpwm_controller");

	ros::NodeHandle n;

	ros::ServiceServer freq_srv =		n.advertiseService 	("set_pwm_frequency", 			set_pwm_frequency);
	ros::ServiceServer config_srv =		n.advertiseService 	("config_servos", 				config_servos);			// 'config' will setup the necessary properties of continuous servos and is helpful for standard servos
	ros::ServiceServer mode_srv =		n.advertiseService 	("config_drive_mode",			config_drive_mode);		// 'mode' specifies which servos are used for motion and which behavior will be applied when driving
	ros::ServiceServer stop_srv =		n.advertiseService 	("stop_servos", 				stop_servos);			// the 'stop' service can be used at any time

	ros::Subscriber abs_sub = 			n.subscribe 		("servos_absolute", 500, 		servos_absolute);		// the 'absolute' topic will be used for standard servo motion and testing of continuous servos
	ros::Subscriber rel_sub = 			n.subscribe 		("servos_proportional", 500, 	servos_proportional);	// the 'proportion' topic will be used for standard servos and continuous rotation aka drive servos
	ros::Subscriber drive_sub = 		n.subscribe 		("servos_drive", 500, 			servos_drive);			// the 'drive' topic will be used for continuous rotation aka drive servos controlled by Twist messages
	
	_load_params();	// loads parameters and performs initialization
	

	ros::spin();

	close (_controller_io_handle);

  return 0;
}

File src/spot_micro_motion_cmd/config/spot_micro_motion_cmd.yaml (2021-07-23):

# Configuration parameters

# Robot wireframe size parameters
# Lengths representening a wireframe model of the robot. All lengths joint to joint
hip_link_length: 0.055 # Straight line distance of the hip link (horizontal leg link)
upper_leg_link_length: 0.1075 # Straight line distance of the upper leg link, joint to joint
lower_leg_link_length: 0.130 # Straight line distance of the lower leg link, joint to joint
body_width: 0.078 # Horizontal width between hip joints
body_length: 0.186 # Length between shoulder joints

# Stance parameters
default_stand_height: 0.155   # Height of robot body center when standing
stand_front_x_offset: 0.015   # Fwb/back offset of front two legs from default stance
stand_back_x_offset: -0.000      # Fwd/back offset of back two legs from default stance
#stand_front_x_offset: -0.010   # Offset better tuned for trot gait
#stand_back_x_offset: -0.010      # Offset better tuned for trot gait
lie_down_height: 0.083        # Height of body center when sitting
lie_down_foot_x_offset: 0.065 # Fwd/back offset of all(?) feet from default stance when sitting 

# Servo parameters
num_servos: 12
servo_max_angle_deg: 82.5
RF_3: {num: 1,  center: 306,range: 339.2,direction:  1, center_angle_deg:  96.81}
RF_2: {num: 2,  center: 306,range: 341.0,direction:  1, center_angle_deg: 17.90}
RF_1: {num: 3,  center: 306,range: 410.7,direction: -1, center_angle_deg:  -55.45}
RB_3: {num: 4,  center: 306,range: 282.3,direction:  1, center_angle_deg:  130.32}
RB_2: {num: 5,  center: 306,range: 317.2,direction:  1, center_angle_deg: 26.01}
RB_1: {num: 6,  center: 306,range: 403.3,direction:  1, center_angle_deg:  10.64}
LB_3: {num: 7,  center: 306,range: 403.3,direction:  1, center_angle_deg: -5.73}
LB_2: {num: 8,  center: 306,range: 419.8,direction:  1, center_angle_deg:  78.21}
LB_1: {num: 9,  center: 306,range: 421.7,direction: -1, center_angle_deg:  -47.35}
LF_3: {num: 10, center: 306,range: 344.7,direction:  1, center_angle_deg: 8.62}
LF_2: {num: 11, center: 306,range: 412.5,direction:  1, center_angle_deg: 9.60}
LF_1: {num: 12, center: 306,range: 403.3,direction:  1, center_angle_deg:  31.09}

# Control Parameters
transit_tau: 0.3 # Time constant in seconds for first order filters during transition state
transit_rl: 0.06 # Body motion rate limit in m/s for transition state
transit_angle_rl: 0.35 # Body motion angular rate limit in rad/s for transition state 
max_fwd_velocity: 0.4
max_side_velocity: 0.4
max_yaw_rate: 0.35

# Gait parameters
z_clearance: 0.050 # Max height of foot during swing phase. Increase to have feet go
                   # higher during swing. Feet travel in a triangular motion during swing
alpha: 0.5 # Controls whether feet are centered within fwd/back motion
beta: 0.5 # Controls whether feet are centered within side to side motion
foot_height_time_constant: 0.02

##################
# GAIT SELECTION #
##################
# Uncomment one set of gait parameters for the desired
# gait to use, and comment out the other set. 

############################################
############## 8 Phase Gait ################
############################################
# Only one leg is ever in swing phase at one time
# 4 swing phases + 4 body motion phases to balance body over
# three legs that will remain in contact with ground
num_phases: 8
rb_contact_phases: [1, 0, 1, 1, 1, 1, 1, 1]
rf_contact_phases: [1, 1, 1, 0, 1, 1, 1, 1]
lf_contact_phases: [1, 1, 1, 1, 1, 1, 1, 0]
lb_contact_phases: [1, 1, 1, 1, 1, 0, 1, 1]
overlap_time: 0.0
swing_time: 0.36
body_shift_phases: [1, 2, 3, 4, 5, 6, 7, 8]
fwd_body_balance_shift: 0.035 # Amount the body center will shift forward when walking
back_body_balance_shift: 0.005 # Amount the body center will shift backward when walking
side_body_balance_shift: 0.015 # Amount the body center will shift side to side when walking 

#################################################
############## 4 Phase Trot Gait ################
#################################################
# 4 Phase gait where the two diagonally oposite legs move in
# tandem together during swing phase
# 2 swing phases + 2 phases where all four feet are on the ground
# num_phases: 4
# rb_contact_phases: [1, 0, 1, 1]
# rf_contact_phases: [1, 1, 1, 0]
# lf_contact_phases: [1, 0, 1, 1]
# lb_contact_phases: [1, 1, 1, 0]
# overlap_time: 0.18
# swing_time: 0.18
# body_shift_phases: [0,0,0,0]
# fwd_body_balance_shift: 0
# back_body_balance_shift: 0
# side_body_balance_shift: 0

# TF Parameter
lidar_x_pos: 0.045 # X offset of lidar coordinate frame center from robot body center
lidar_y_pos: 0.0 # Y offset of lidar coordinate frame center from robot body center
lidar_z_pos: 0.085 # Z offset of lidar coordinate frame center from robot body center
lidar_yaw_angle: 180 # Angle in degrees of yaw angle of the mounted lidar. Pitch and roll are assumed to be 0
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

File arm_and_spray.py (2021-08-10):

#!/usr/bin/env python3

import json
import platform
import os
from time import time, monotonic,sleep
import cv2
import numpy as np
import depthai
from depthai_helpers.version_check import check_depthai_version
from depthai_helpers.object_tracker_handler import show_tracklets
from depthai_helpers.config_manager import DepthConfigManager
from depthai_helpers.arg_manager import CliArgs

from adafruit_servokit import ServoKit    #https://circuitpython.readthedocs.io/projects/servokit/en/latest/
import threading

print('Using depthai module from: ', depthai.__file__)
print('Depthai version installed: ', depthai.__version__)
check_depthai_version()
is_rpi = platform.machine().startswith('arm') or platform.machine().startswith('aarch64')
global args, cnn_model2
# motor controlling
import RPi.GPIO as GPIO          
from time import sleep

in1 = 23
in2 = 24

temp1=1

GPIO.setmode(GPIO.BCM)
GPIO.setup(in1,GPIO.OUT)
GPIO.setup(in2,GPIO.OUT)

GPIO.output(in1,GPIO.LOW)
GPIO.output(in2,GPIO.LOW)
print("\n")
print("The default speed & direction of motor is LOW & Forward.....")
print("r-run s-stop f-forward b-backward l-low m-medium h-high e-exit")
print("\n")    



def inverse_kinematics(x,y,a1,a2):
    x2 = np.square(x)
    y2 = np.square(y)
    a = np.square(a1)
    b = np.square(a2)
    c = 2 * a1 * a2
    q2 = np.arccos(x2 + y2 - a - b / c)
    q1 = arctan(y2/x2) - np.arctan(a2 * np.sin(q2) / (a1 + a2 * np.cos(q2)))
    q1 = np.degrees(q1)
    q2 = np.degrees(q2)
    return q1,q2

#Constants
nbPCAServo=1
#Parameters
MIN_IMP  =[500, 500, 500, 500, 500, 500, 500, 500, 500, 500, 500, 500, 500, 500, 500, 500]
MAX_IMP  =[2500, 2500, 2500, 2500, 2500, 2500, 2500, 2500, 2500, 2500, 2500, 2500, 2500, 2500, 2500, 2500]
MIN_ANG  =[0, 0, 0, 0, 0, 0, 0, 0, 0, 0, 0, 0, 0, 0, 0, 0,0]
MAX_ANG  =[180, 180, 180, 180, 180, 180, 180, 180, 180, 180, 180, 180, 180, 180, 180, 180,180]
#Objects
pca = ServoKit(channels=16)
# function init 
def init():
    for i in range(nbPCAServo):
        pca.servo[i].set_pulse_width_range(MIN_IMP[i] , MAX_IMP[i])



# function motor 2 
def m2(motor_angle):
        pca.servo[3].angle = motor_angle
        sleep(0.5)
        # Forward
        GPIO.output(in1,GPIO.LOW)
        GPIO.output(in2,GPIO.HIGH)
        sleep(5)
        # Stop
        GPIO.output(in1,GPIO.LOW)
        GPIO.output(in2,GPIO.LOW)
        sleep(0.5)
# function motor 3
def m3(motor_angle):
        pca.servo[7].angle = motor_angle
        sleep(0.5)
class DepthAI:
    global is_rpi
    process_watchdog_timeout = 10  # seconds
    nnet_packets = None
    data_packets = None
    runThread = True

    def reset_process_wd(self):
        global wd_cutoff
        wd_cutoff = monotonic() + self.process_watchdog_timeout
        return

    def on_trackbar_change(self, value):
        self.device.send_disparity_confidence_threshold(value)
        return

    def stopLoop(self):
        self.runThread = False

    def startLoop(self):
        cliArgs = CliArgs()
        args = vars(cliArgs.parse_args())

        configMan = DepthConfigManager(args)
        if is_rpi and args['pointcloud']:
            raise NotImplementedError("Point cloud visualization is currently not supported on RPI")
        # these are largely for debug and dev.
        cmd_file, debug_mode = configMan.getCommandFile()
        usb2_mode = configMan.getUsb2Mode()

        # decode_nn and show_nn are functions that are dependent on the neural network that's being run.
        decode_nn = configMan.decode_nn
        show_nn = configMan.show_nn

        # Labels for the current neural network. They are parsed from the blob config file.
        labels = configMan.labels
        NN_json = configMan.NN_config

        # This json file is sent to DepthAI. It communicates what options you'd like to enable and what model you'd like to run.
        config = configMan.jsonConfig

        # Create a list of enabled streams ()
        stream_names = [stream if isinstance(stream, str) else stream['name'] for stream in configMan.stream_list]

        enable_object_tracker = 'object_tracker' in stream_names

        # grab video file, if option exists
        video_file = configMan.video_file

        self.device = None
        if debug_mode:
            print('Cmd file: ', cmd_file, ' args["device_id"]: ', args['device_id'])
            self.device = depthai.Device(cmd_file, args['device_id'])
        else:
            self.device = depthai.Device(args['device_id'], usb2_mode)

        print(stream_names)
        print('Available streams: ' + str(self.device.get_available_streams()))

        # create the pipeline, here is the first connection with the device
        p = self.device.create_pipeline(config=config)

        if p is None:
            print('Pipeline is not created.')
            exit(3)

        nn2depth = self.device.get_nn_to_depth_bbox_mapping()

        t_start = time()
        frame_count = {}
        frame_count_prev = {}
        nnet_prev = {}
        nnet_prev["entries_prev"] = {}
        nnet_prev["nnet_source"] = {}
        frame_count['nn'] = {}
        frame_count_prev['nn'] = {}

        NN_cams = {'rgb', 'left', 'right'}

        for cam in NN_cams:
            nnet_prev["entries_prev"][cam] = None
            nnet_prev["nnet_source"][cam] = None
            frame_count['nn'][cam] = 0
            frame_count_prev['nn'][cam] = 0

        stream_windows = []
        for s in stream_names:
            if s == 'previewout':
                for cam in NN_cams:
                    stream_windows.append(s + '-' + cam)
            else:
                stream_windows.append(s)

        for w in stream_windows:
            frame_count[w] = 0
            frame_count_prev[w] = 0

        tracklets = None

        self.reset_process_wd()

        time_start = time()

        def print_packet_info_header():
            print('[hostTimestamp streamName] devTstamp seq camSrc width height Bpp')
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

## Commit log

2021-07-23 gyro visualization
2021-08-09 Arm print files
    [Arm 1.stl, Arm 1B.stl, Base Motor Support.stl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]
2021-08-10 arm documents
